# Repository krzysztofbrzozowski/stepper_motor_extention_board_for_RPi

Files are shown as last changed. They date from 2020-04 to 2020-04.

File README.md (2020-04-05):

# Stepper motor extention board for Raspberry Pi

Stepper motor extention board for Raspberry Pi Krzysztof Brzozowski (https://krzysztofbrzozowski.pl/projekt/steronik-silnikow-krokowych-rpi-kontroler-aku-usbc/)

Stepper motor extention board for Raspberry Pi Krzysztof Brzozowski (https://krzysztofbrzozowski.pl/projekt/steronik-silnikow-krokowych-rpi-kontroler-aku-usbc/)

Simple extension board for controlling stepper motors (up to 3). Board contains Li-Po battery controller (2-4s). It is also possible to charge battery via USB C. Basic firmware you can find here [stepper_motor_extention_board_firmware.git](https://github.com/krzysztofbrzozowski/stepper_motor_extention_board_firmware.git).
Controller is using simple algorithm for controlling ttepper motors [packets table](https://krzysztofbrzozowski.pl/media/2020/04/05/packet_encoding.png).

Whole project is describerd in polish on my webpage: https://krzysztofbrzozowski.pl/projekt/steronik-silnikow-krokowych-rpi-kontroler-aku-usbc/

## Repository Contents

- **/PCB** - Eagle PCB and schematic files, schematic in PDF

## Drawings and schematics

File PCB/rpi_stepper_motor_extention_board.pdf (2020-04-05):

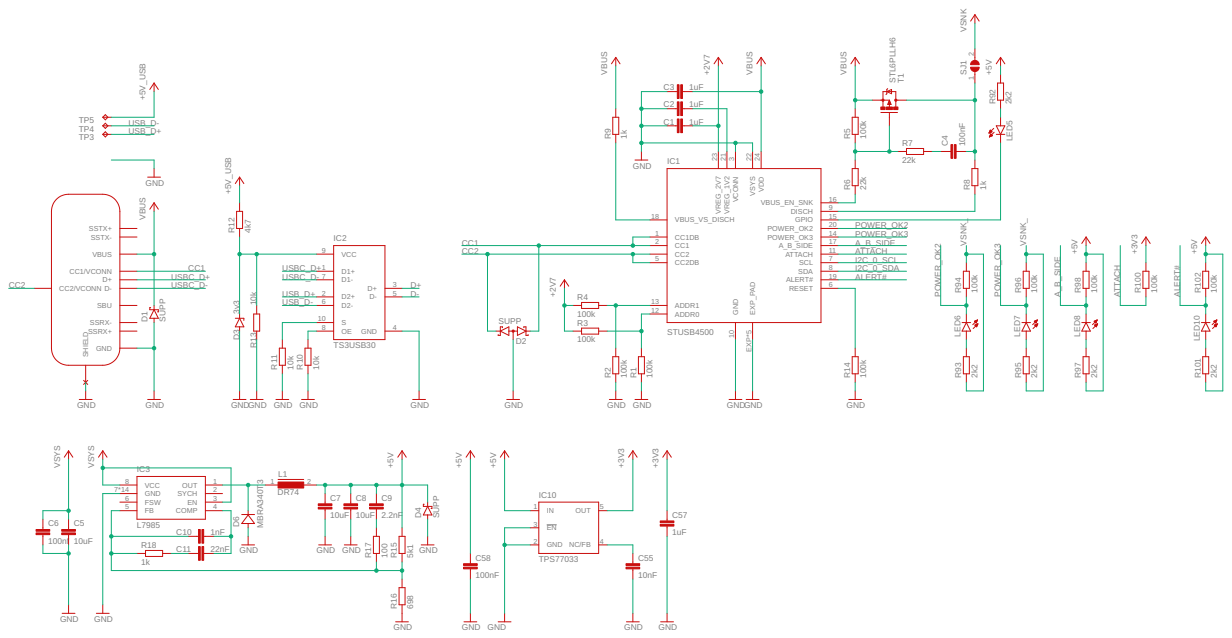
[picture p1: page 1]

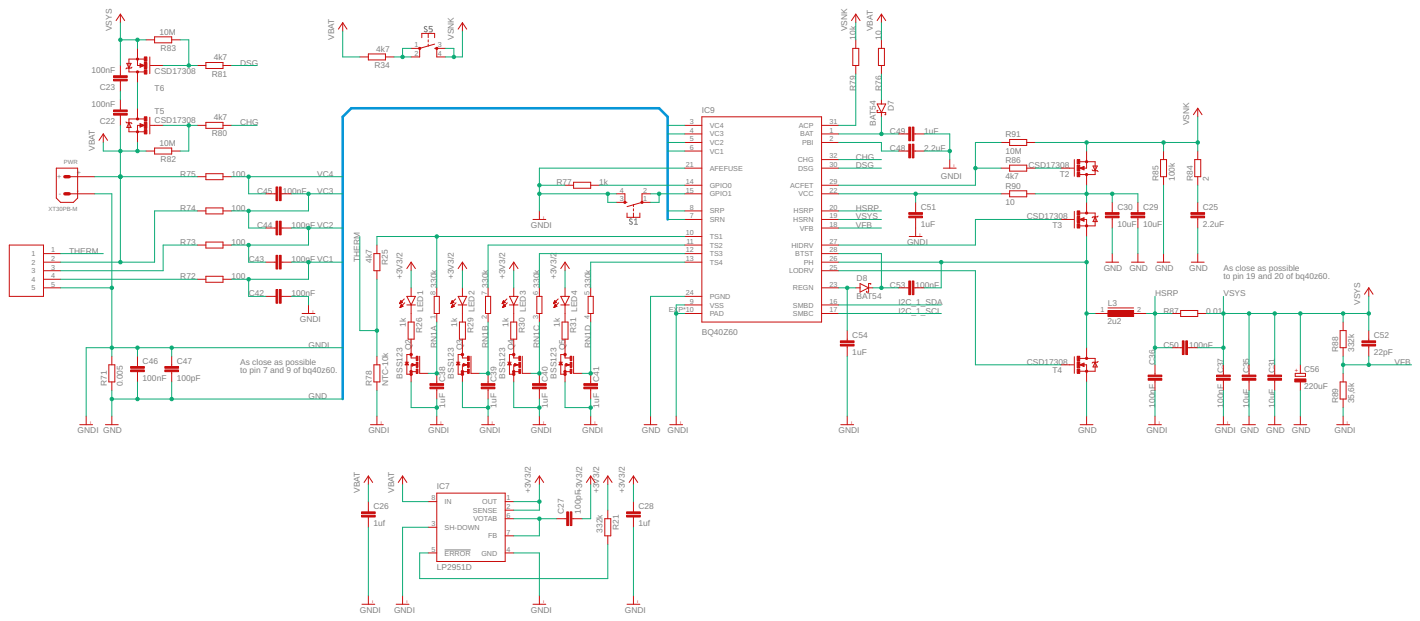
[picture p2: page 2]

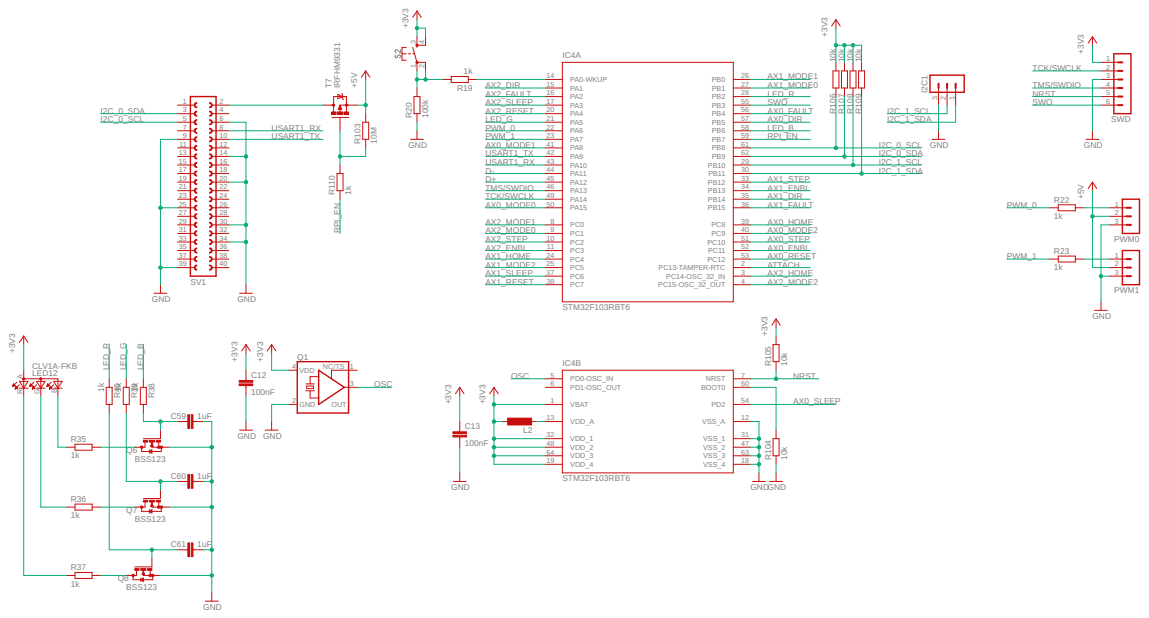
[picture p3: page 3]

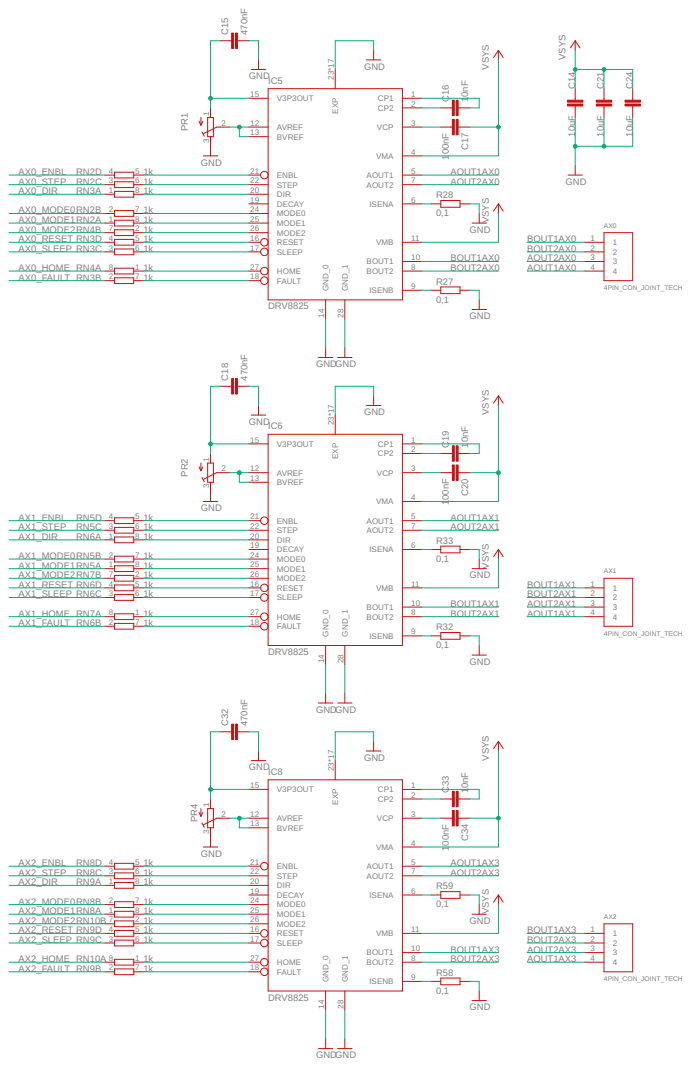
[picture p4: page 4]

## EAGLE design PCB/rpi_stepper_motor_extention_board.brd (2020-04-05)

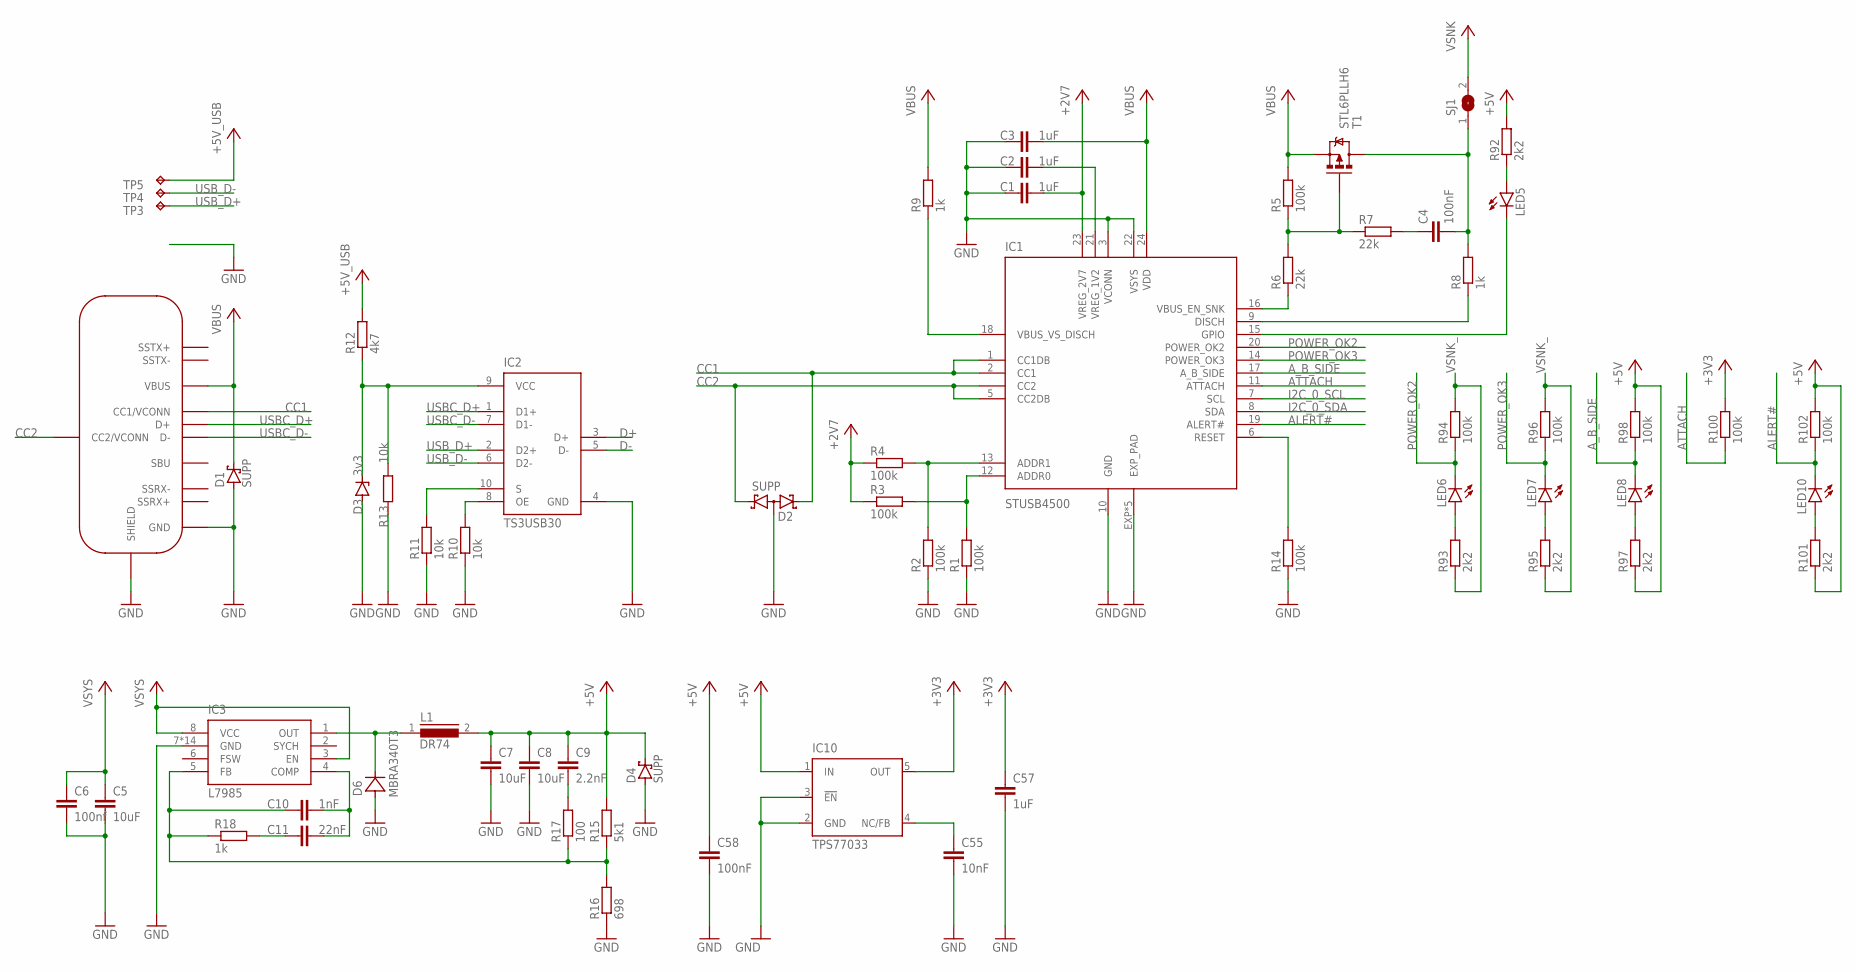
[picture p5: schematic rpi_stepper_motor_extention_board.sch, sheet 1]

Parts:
C1, C2, C57: 1uF; C0402K
C3: 1uF; C0603
C4, C58: 100nF; C0402K
C5: 10uF; C1206K
C6: 100nf; C0402K
C7, C8: 10uF; C1210
C9: 2.2nF; C0402K
C10: 1nF; C0402K
C11: 22nF; C0402K
C55: 10nF; C0402K
CON1: USB-TYPE-CHYBRID; USB-TYPE-C-HYBRID
D1, D4: SUPP; SOD123FL
D2: SUPP; SOT23
D3: 3v3; SOD80C
D6: MBRA340T3; SMA
IC1: STUSB4500; QFN50P400X400X90-25T270
IC2: TS3USB30; QFN40P180X145X55-10
IC3: L7985; SOIC127P600X170-8
IC10: TPS77033; SOT23-DBV
L1: DR74
LED5, LED6, LED7, LED8, LED10: LEDCHIPLED_0603; CHIPLED_0603
R1, R2, R3, R4, R5, R14, R94, R96, R98, R100, R102: 100k; R0402
R6, R7: 22k; R0402
R8, R9: 1k; R0603
R10, R11, R13: 10k; R0402
R12: 4k7; R0402
R15: 5k1; R0805
R16: 698; R0805
R17: 100; R0402
R18: 1k; R0402
R92, R93, R95, R97, R101: 2k2; R0402
SJ1: SJ
T1: STL6PLLH6; POWERPAK1212-8
TP3, TP4, TP5: TPB1,27; B1,27

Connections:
+2V7: C1.2, IC1.23 (VREG_2V7), R3.1, R4.1
+3V3: C57.1, IC10.5 (OUT), R100.2; also elsewhere on the board
+5V: C7.1, C8.1, C9.1, C58.1, D4.C, IC10.1 (IN), L1.2, R15.2, R92.2, R97.1, R98.2, R101.1, R102.2; also elsewhere on the board
+5V_USB: R12.2, TP5.TP
ALERT#: IC1.19 (ALERT#), LED10.C, R102.1
ATTACH: IC1.11 (ATTACH), R100.1; also elsewhere on the board
A_B_SIDE: IC1.17 (A_B_SIDE), LED8.C, R98.1
CC1: CON1.5 (CC1/VCONN), D2.2 (K2), IC1.1 (CC1DB), IC1.2 (CC1)
CC2: CON1.B5 (CC2/VCONN), D2.1 (K1), IC1.4 (CC2), IC1.5 (CC2DB)
D+: IC2.3 (D+); also elsewhere on the board
D-: IC2.5 (D-); also elsewhere on the board
GND: C1.1, C2.1, C3.1, C5.2, C6.2, C7.2, C8.2, C55.2, C57.2, C58.2, CON1.1 (GND), CON1.12 (GND), CON1.B1 (GND), CON1.B12 (GND), CON1.P$1 (SHIELD), CON1.P$2 (SHIELD), CON1.P$3 (SHIELD), CON1.P$4 (SHIELD), CON1.P$7 (SHIELD), CON1.P$8 (SHIELD), CON1.P$9 (SHIELD), CON1.P$10 (SHIELD), CON1.P$11 (SHIELD), CON1.P$12 (SHIELD), CON1.P$13 (SHIELD), CON1.P$14 (SHIELD), CON1.P$15 (SHIELD), CON1.P$16 (SHIELD), CON1.P$17 (SHIELD), CON1.P$18 (SHIELD), CON1.P$19 (SHIELD), CON1.P$20 (SHIELD), CON1.P$21 (SHIELD), CON1.P$22 (SHIELD), CON1.P$23 (SHIELD), CON1.P$24 (SHIELD), CON1.P$25 (SHIELD), CON1.P$26 (SHIELD), CON1.P$27 (SHIELD), CON1.P$28 (SHIELD), CON1.P$29 (SHIELD), CON1.P$30 (SHIELD), CON1.P$31 (SHIELD), CON1.P$32 (SHIELD), CON1.P$33 (SHIELD), CON1.P$34 (SHIELD), CON1.P$35 (SHIELD), D1.A, D2.3 (AA), D3.A, D4.A, D6.A, IC1.3 (VCONN), IC1.10 (GND), IC1.22 (VSYS), IC1.EXP (EXP_PAD), IC1.P$1 (EXP_PAD), IC1.P$2 (EXP_PAD), IC1.P$3 (EXP_PAD), IC1.P$4 (EXP_PAD), IC2.4 (GND), IC3.7 (GND), IC3.EXP (GND), IC3.P$1 (GND), IC3.P$2 (GND), IC3.P$3 (GND), IC3.P$4 (GND), IC3.P$5 (GND), IC3.P$6 (GND), IC3.P$7 (GND), IC3.P$8 (GND), IC3.P$9 (GND), IC3.P$10 (GND), IC3.P$11 (GND), IC3.P$12 (GND), IC10.2 (GND), IC10.3 (!EN), R1.1, R2.1, R10.1, R11.1, R13.2, R14.1, R16.1; also elsewhere on the board
I2C_0_SCL: IC1.7 (SCL); also elsewhere on the board
I2C_0_SDA: IC1.8 (SDA); also elsewhere on the board
unnamed: IC1.12 (ADDR0), R1.2, R3.2
unnamed: IC1.13 (ADDR1), R2.2, R4.2
unnamed: C2.2, IC1.21 (VREG_1V2)
unnamed: C4.1, R7.2
unnamed: IC1.16 (VBUS_EN_SNK), R6.1
unnamed: R5.1, R6.2, R7.1, T1.G
unnamed: IC1.18 (VBUS_VS_DISCH), R9.1
unnamed: IC1.9 (DISCH), R8.1
unnamed: IC2.8 (OE), R10.2
unnamed: IC2.10 (S), R11.2
unnamed: D6.C, IC3.1 (OUT), L1.1
unnamed: D3.C, IC2.9 (VCC), R12.1, R13.1
unnamed: IC1.6 (RESET), R14.2
unnamed: C10.1, IC3.5 (FB), R15.1, R16.2, R17.1, R18.1
unnamed: C9.2, R17.2
unnamed: C10.2, C11.2, IC3.4 (COMP)
unnamed: C11.1, R18.2
unnamed: C55.1, IC10.4 (NC/FB)
unnamed: LED5.A, R92.1
unnamed: LED6.A, R93.2
unnamed: LED10.A, R101.2
unnamed: LED7.A, R95.2
unnamed: IC1.15 (GPIO), LED5.C
unnamed: LED8.A, R97.2
POWER_OK2: IC1.20 (POWER_OK2), LED6.C, R94.1
POWER_OK3: IC1.14 (POWER_OK3), LED7.C, R96.1
USBC_D+: CON1.6 (D+), CON1.B6 (D+), IC2.1 (D1+)
USBC_D-: CON1.7 (D-), CON1.B7 (D-), IC2.7 (D1-)
USB_D+: IC2.2 (D2+), TP3.TP
USB_D-: IC2.6 (D2-), TP4.TP
VBUS: C3.2, CON1.4 (VBUS), CON1.9 (VBUS), CON1.B4 (VBUS), CON1.B9 (VBUS), D1.C, IC1.24 (VDD), R5.2, R9.2, T1.S1 (S), T1.S2 (S), T1.S3 (S)
VSNK: SJ1.2; also elsewhere on the board
VSNK_: C4.2, R8.2, R93.1, R94.2, R95.1, R96.2, SJ1.1, T1.D1 (D), T1.D2 (D), T1.D3 (D), T1.D4 (D), T1.DPAD (D)
VSYS: C5.1, C6.1, IC3.3 (EN), IC3.8 (VCC); also elsewhere on the board

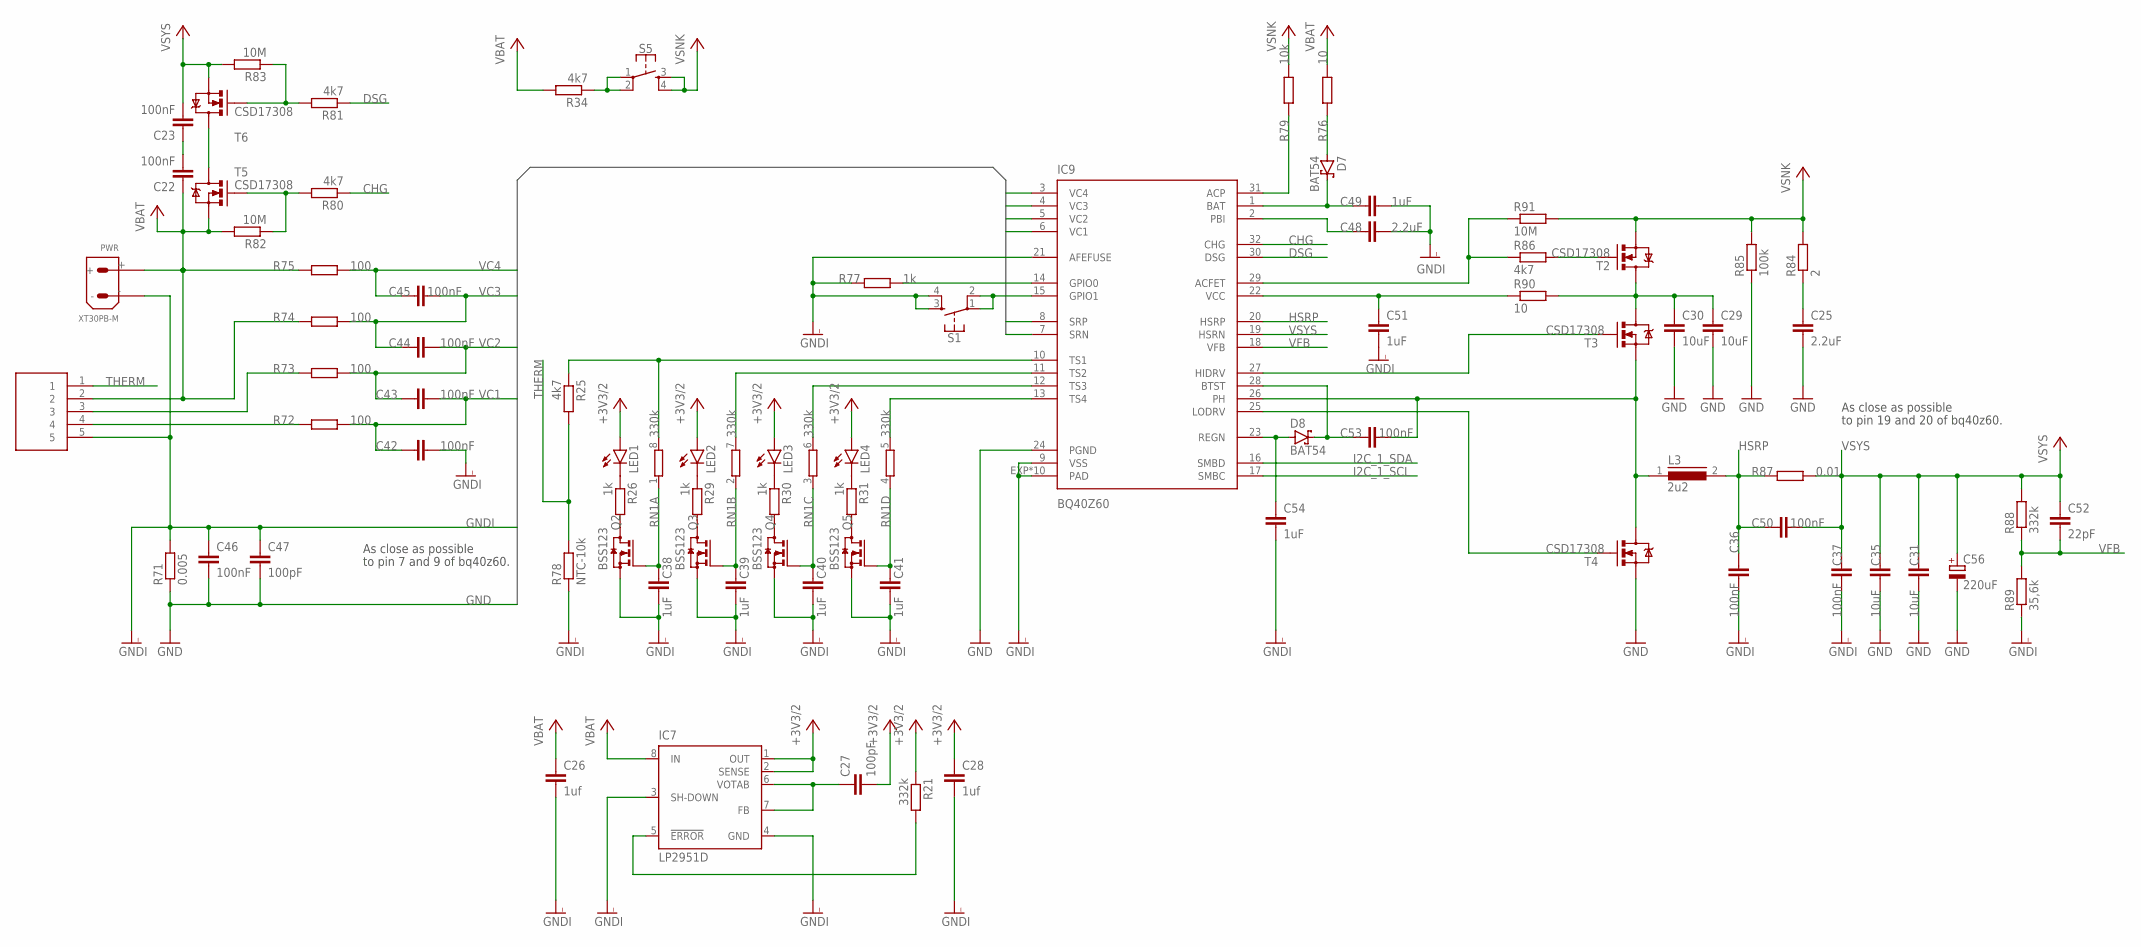
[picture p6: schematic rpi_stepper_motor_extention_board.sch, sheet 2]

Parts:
C22, C23: 100nF; C0603K
C25, C48: 2.2uF; C0603K
C26, C28: 1uf; C0402
C27, C47: 100pF; C0402
C29, C30, C31, C35: 10uF; C1206K
C36, C37, C42, C43, C44, C45, C50, C53: 100nF; C0402K
C38, C39, C40, C41: 1uF; C0402K
C46: 100nF; C0402
C49, C51, C54: 1uF; C0603K
C52: 22pF; C0402K
C56: 220uF; 153CLV-0605
D7, D8: BAT54; SOD123FL
IC7: LP2951D; SO08
IC9: BQ40Z60; QFN50P500X500X100-33T345
L3: 2u2; DR74
LED1, LED2, LED3, LED4: LEDCHIPLED_0603; CHIPLED_0603
PWR: XT30PB-M
Q2, Q3, Q4, Q5: BSS123; SOT23
R21: 332k; R0402
R25, R34, R80, R81, R86: 4k7; R0402
R26, R29, R30, R31, R77: 1k; R0402
R71: 0.005; R2010
R72, R73, R74, R75: 100; R0603
R76: 10; R0402
R78: NTC-10k; R0603
R79: 10k; R0402
R82, R83, R91: 10M; R0402
R84: 2; R0603
R85: 100k; R0402
R87: 0.01; R2512
R88: 332k; R0805
R89: 35,6k; R0805
R90: 10; R1206
RN1: 330k; 0603-ARC
S1, S5: MOMENTARY-SWITCH-SPST-2-SMD-4.6X2.8MM; TACTILE_SWITCH_SMD_4.6X2.8MM
T2, T3, T4, T5, T6: CSD17308; POWERPAK1212-8
U$1: 5PIN_CON_JOINT_TECH

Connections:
+3V3/2: C27.2, C28.1, IC7.1 (OUT), IC7.2 (SENSE), LED1.A, LED2.A, LED3.A, LED4.A, R21.1
CHG: IC9.32 (CHG), R80.1
DSG: IC9.30 (DSG), R81.1
GND: C25.2, C29.2, C30.2, C31.2, C35.2, C46.2, C47.2, C56.-, IC9.7 (SRN), IC9.24 (PGND), R71.1, R85.1, T4.S1 (S), T4.S2 (S), T4.S3 (S); also elsewhere on the board
GNDI: C26.2, C28.2, C36.2, C37.2, C38.2, C39.2, C40.2, C41.2, C42.1, C46.1, C47.1, C48.2, C49.2, C51.2, C54.2, IC7.3 (SH-DOWN), IC7.4 (GND), IC9.8 (SRP), IC9.9 (VSS), IC9.21 (AFEFUSE), IC9.EXP (PAD), IC9.P$1 (PAD), IC9.P$2 (PAD), IC9.P$3 (PAD), IC9.P$4 (PAD), IC9.P$5 (PAD), IC9.P$6 (PAD), IC9.P$7 (PAD), IC9.P$8 (PAD), IC9.P$9 (PAD), PWR.-, Q2.2 (S), Q3.2 (S), Q4.2 (S), Q5.2 (S), R71.2, R77.1, R78.1, R89.1, S1.3, S1.4, U$1.5
HSRP: C36.1, C50.1, IC9.20 (HSRP), L3.2, R87.1
I2C_1_SCL: IC9.17 (SMBC); also elsewhere on the board
I2C_1_SDA: IC9.16 (SMBD); also elsewhere on the board
unnamed: LED1.C, R26.1
unnamed: LED2.C, R29.1
unnamed: LED3.C, R30.1
unnamed: LED4.C, R31.1
unnamed: C27.1, IC7.6 (VOTAB), IC7.7 (FB)
unnamed: Q2.3 (D), R26.2
unnamed: Q3.3 (D), R29.2
unnamed: IC7.5 (!ERROR), R21.2
unnamed: Q5.3 (D), R31.2
unnamed: Q4.3 (D), R30.2
unnamed: R34.1, S5.1, S5.2
unnamed: C38.1, Q2.1 (G), RN1.1
unnamed: C48.1, IC9.2 (PBI)
unnamed: IC9.10 (TS1), R25.1, RN1.8 (2)
unnamed: IC9.11 (TS2), RN1.7 (2)
unnamed: IC9.12 (TS3), RN1.6 (2)
unnamed: IC9.13 (TS4), RN1.5 (2)
unnamed: C39.1, Q3.1 (G), RN1.2 (1)
unnamed: D7.A, R76.1
unnamed: R72.1, U$1.4
unnamed: C40.1, Q4.1 (G), RN1.3 (1)
unnamed: C41.1, Q5.1 (G), RN1.4 (1)
unnamed: C49.1, D7.C, IC9.1 (BAT)
unnamed: R73.1, U$1.3
unnamed: IC9.14 (GPIO0), R77.2
unnamed: IC9.15 (GPIO1), S1.1, S1.2
unnamed: IC9.31 (ACP), R79.1
unnamed: T5.D1 (D), T5.D2 (D), T5.D3 (D), T5.D4 (D), T5.DPAD (D), T6.D1 (D), T6.D2 (D), T6.D3 (D), T6.D4 (D), T6.DPAD (D)
unnamed: R80.2, R82.1, T5.G
unnamed: R81.2, R83.1, T6.G
unnamed: C25.1, R84.1
unnamed: C22.2, C23.1
unnamed: C29.1, C30.1, R90.2, T2.D1 (D), T2.D2 (D), T2.D3 (D), T2.D4 (D), T2.DPAD (D), T3.D1 (D), T3.D2 (D), T3.D3 (D), T3.D4 (D), T3.DPAD (D)
unnamed: C53.2, IC9.26 (PH), L3.1, T3.S1 (S), T3.S2 (S), T3.S3 (S), T4.D1 (D), T4.D2 (D), T4.D3 (D), T4.D4 (D), T4.DPAD (D)
unnamed: R86.2, T2.G
unnamed: IC9.27 (HIDRV), T3.G
unnamed: IC9.25 (LODRV), T4.G
unnamed: IC9.29 (ACFET), R86.1, R91.1
unnamed: C51.1, IC9.22 (VCC), R90.1
unnamed: C54.1, D8.A, IC9.23 (REGN)
unnamed: C53.1, D8.C, IC9.28 (BTST)
THERM: R25.2, R78.2, U$1.1
VBAT: C22.1, C26.1, IC7.8 (IN), PWR.+, R34.2, R74.1, R75.1, R76.2, R82.2, T5.S1 (S), T5.S2 (S), T5.S3 (S), U$1.2
VC1: C42.2, C43.1, IC9.6 (VC1), R72.2
VC2: C43.2, C44.1, IC9.5 (VC2), R73.2
VC3: C44.2, C45.1, IC9.4 (VC3), R74.2
VC4: C45.2, IC9.3 (VC4), R75.2
VFB: C52.2, IC9.18 (VFB), R88.1, R89.2
VSNK: R79.2, R84.2, R85.2, R91.2, S5.3, S5.4, T2.S1 (S), T2.S2 (S), T2.S3 (S); also elsewhere on the board
VSYS: C23.2, C31.1, C35.1, C37.1, C50.2, C52.1, C56.+, IC9.19 (HSRN), R83.2, R87.2, R88.2, T6.S1 (S), T6.S2 (S), T6.S3 (S); also elsewhere on the board

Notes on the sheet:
As close as possible
to pin 7 and 9 of bq40z60.
to pin 19 and 20 of bq40z60.

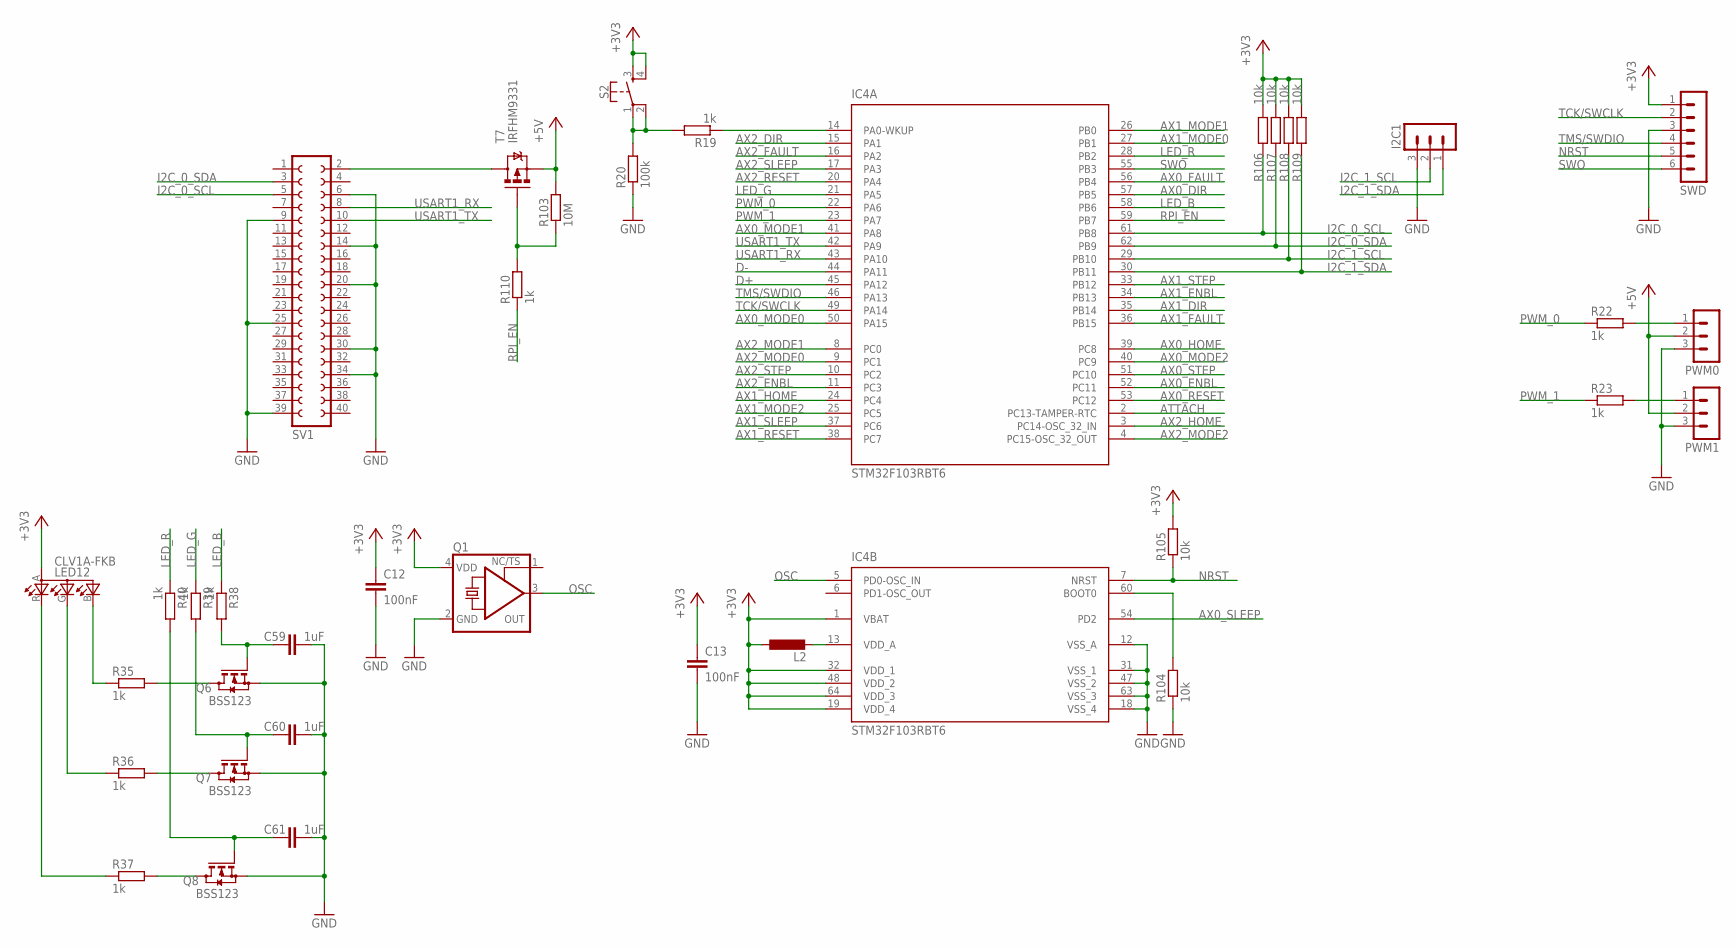
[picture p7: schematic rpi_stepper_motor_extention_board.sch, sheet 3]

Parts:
C12, C13: 100nF; C0402K
C59, C60, C61: 1uF; C0402K
I2C1: MA03-1
IC4: STM32F103RBT6; QFP50P1200X1200X160-64
L2: L-EUL2012C; L2012C
LED12: CLV1A-FKB
PWM0, PWM1: MA03-1
Q1: KXO-PXO/XO-V95; 2.5X2.0_KXO-V95
Q6, Q7, Q8: BSS123; SOT23
R19, R22, R23, R35, R36, R37, R38, R39, R40, R110: 1k; R0402
R20: 100k; R0402
R103: 10M; R0402
R104, R105, R106, R107, R108, R109: 10k; R0402
S2: MOMENTARY-SWITCH-SPST-2-SMD-4.6X2.8MM; TACTILE_SWITCH_SMD_4.6X2.8MM
SV1: FE20-2
SWD: MA06-1
T7: IRFHM9331; POWERPAK1212-8

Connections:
+3V3: C12.1, C13.1, IC4.1 (VBAT), IC4.19 (VDD_4), IC4.32 (VDD_1), IC4.48 (VDD_2), IC4.64 (VDD_3), L2.1, LED12.A (ANODE), Q1.4 (VDD), R105.2, R106.2, R107.2, R108.2, R109.2, S2.3, S2.4, SWD.1; also elsewhere on the board
+5V: PWM0.2, PWM1.2, R103.2, T7.S1 (S), T7.S2 (S), T7.S3 (S); also elsewhere on the board
ATTACH: IC4.2 (PC13-TAMPER-RTC); also elsewhere on the board
AX0_DIR: IC4.57 (PB5); also elsewhere on the board
AX0_ENBL: IC4.52 (PC11); also elsewhere on the board
AX0_FAULT: IC4.56 (PB4); also elsewhere on the board
AX0_HOME: IC4.39 (PC8); also elsewhere on the board
AX0_MODE0: IC4.50 (PA15); also elsewhere on the board
AX0_MODE1: IC4.41 (PA8); also elsewhere on the board
AX0_MODE2: IC4.40 (PC9); also elsewhere on the board
AX0_RESET: IC4.53 (PC12); also elsewhere on the board
AX0_SLEEP: IC4.54 (PD2); also elsewhere on the board
AX0_STEP: IC4.51 (PC10); also elsewhere on the board
AX1_DIR: IC4.35 (PB14); also elsewhere on the board
AX1_ENBL: IC4.34 (PB13); also elsewhere on the board
AX1_FAULT: IC4.36 (PB15); also elsewhere on the board
AX1_HOME: IC4.24 (PC4); also elsewhere on the board
AX1_MODE0: IC4.27 (PB1); also elsewhere on the board
AX1_MODE1: IC4.26 (PB0); also elsewhere on the board
AX1_MODE2: IC4.25 (PC5); also elsewhere on the board
AX1_RESET: IC4.38 (PC7); also elsewhere on the board
AX1_SLEEP: IC4.37 (PC6); also elsewhere on the board
AX1_STEP: IC4.33 (PB12); also elsewhere on the board
AX2_DIR: IC4.15 (PA1); also elsewhere on the board
AX2_ENBL: IC4.11 (PC3); also elsewhere on the board
AX2_FAULT: IC4.16 (PA2); also elsewhere on the board
AX2_HOME: IC4.3 (PC14-OSC_32_IN); also elsewhere on the board
AX2_MODE0: IC4.9 (PC1); also elsewhere on the board
AX2_MODE1: IC4.8 (PC0); also elsewhere on the board
AX2_MODE2: IC4.4 (PC15-OSC_32_OUT); also elsewhere on the board
AX2_RESET: IC4.20 (PA4); also elsewhere on the board
AX2_SLEEP: IC4.17 (PA3); also elsewhere on the board
AX2_STEP: IC4.10 (PC2); also elsewhere on the board
D+: IC4.45 (PA12); also elsewhere on the board
D-: IC4.44 (PA11); also elsewhere on the board
GND: C12.2, C13.2, C59.2, C60.2, C61.2, I2C1.3, IC4.12 (VSS_A), IC4.18 (VSS_4), IC4.31 (VSS_1), IC4.47 (VSS_2), IC4.63 (VSS_3), PWM0.3, PWM1.3, Q1.2 (GND), Q6.2 (S), Q7.2 (S), Q8.2 (S), R20.1, R104.1, SV1.6, SV1.9, SV1.14, SV1.20, SV1.25, SV1.30, SV1.34, SV1.39, SWD.3; also elsewhere on the board
I2C_0_SCL: IC4.61 (PB8), R106.1, SV1.5; also elsewhere on the board
I2C_0_SDA: IC4.62 (PB9), R107.1, SV1.3; also elsewhere on the board
I2C_1_SCL: I2C1.2, IC4.29 (PB10), R108.1; also elsewhere on the board
I2C_1_SDA: I2C1.1, IC4.30 (PB11), R109.1; also elsewhere on the board
LED_B: IC4.58 (PB6), R38.1
LED_G: IC4.21 (PA5), R39.1
LED_R: IC4.28 (PB2), R40.1
unnamed: IC4.13 (VDD_A), L2.2
unnamed: LED12.G (CGREEN), R36.1
unnamed: C59.1, Q6.1 (G), R38.2
unnamed: IC4.14 (PA0-WKUP), R19.1
unnamed: LED12.R (CRED), R37.1
unnamed: LED12.B (CBLUE), R35.1
unnamed: Q8.3 (D), R37.2
unnamed: Q7.3 (D), R36.2
unnamed: Q6.3 (D), R35.2
unnamed: C60.1, Q7.1 (G), R39.2
unnamed: C61.1, Q8.1 (G), R40.2
unnamed: SV1.2, T7.D1 (D), T7.D2 (D), T7.D3 (D), T7.D4 (D), T7.DPAD (D)
unnamed: IC4.60 (BOOT0), R104.2
unnamed: R103.1, R110.2, T7.G
unnamed: R19.2, R20.2, S2.1, S2.2
unnamed: PWM0.1, R22.2
unnamed: PWM1.1, R23.2
NRST: IC4.7 (NRST), R105.1, SWD.5
OSC: IC4.5 (PD0-OSC_IN), Q1.3 (OUT)
PWM_0: IC4.22 (PA6), R22.1
PWM_1: IC4.23 (PA7), R23.1
RPI_EN: IC4.59 (PB7), R110.1
SWO: IC4.55 (PB3), SWD.6
TCK/SWCLK: IC4.49 (PA14), SWD.2
TMS/SWDIO: IC4.46 (PA13), SWD.4
USART1_RX: IC4.43 (PA10), SV1.8
USART1_TX: IC4.42 (PA9), SV1.10

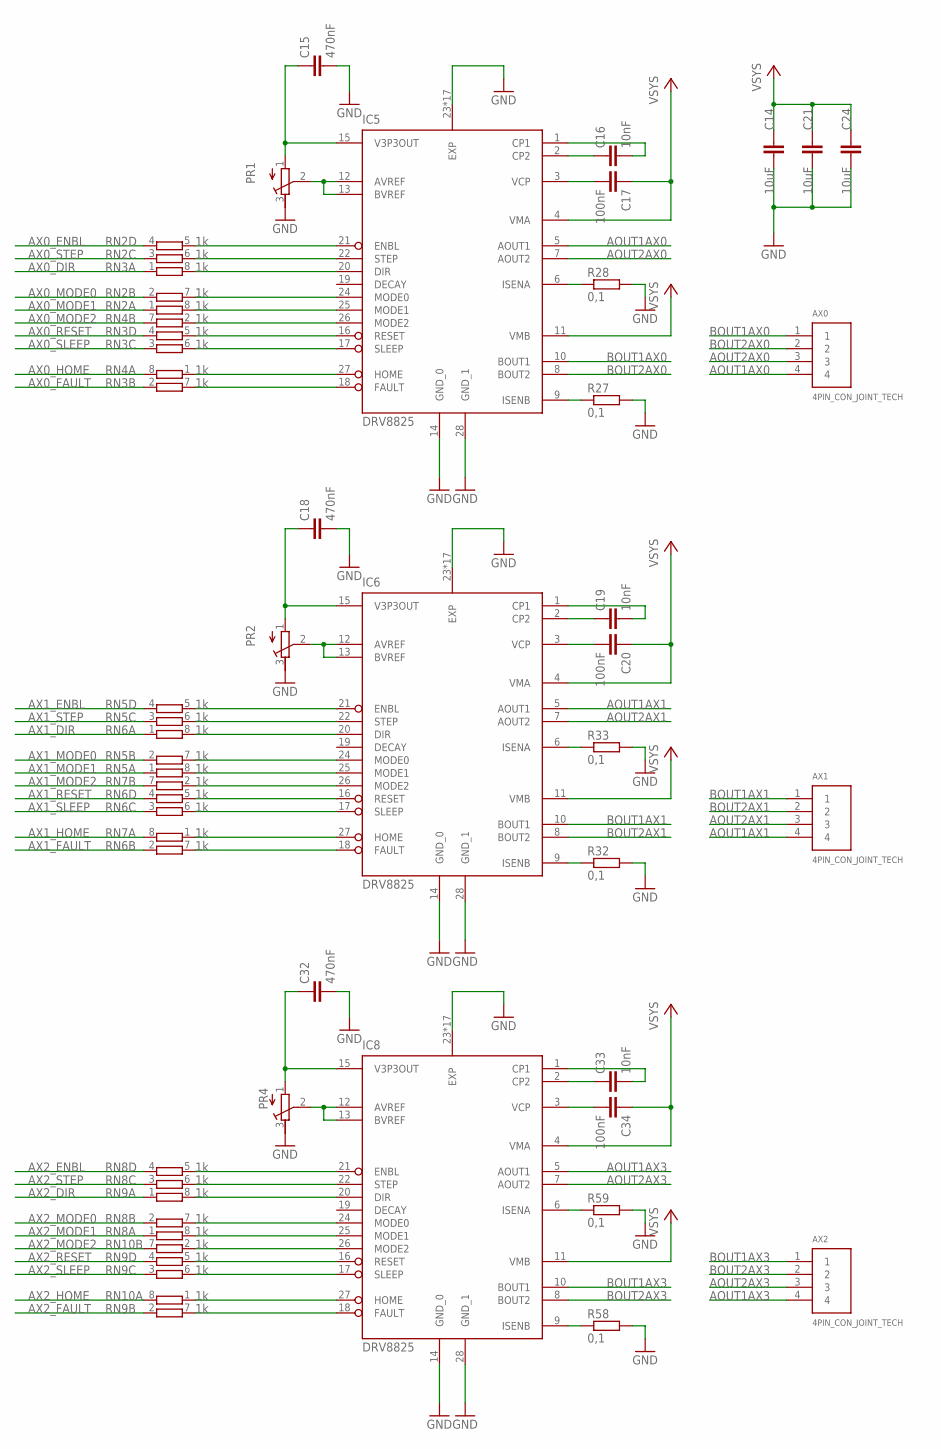
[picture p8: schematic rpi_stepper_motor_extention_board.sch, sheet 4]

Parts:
AX0, AX1, AX2: 4PIN_CON_JOINT_TECH
C14, C21, C24: 10uF; C1206K
C15, C18, C32: 470nF; C0402K
C16, C19, C33: 10nF; C0402K
C17, C20, C34: 100nF; C0402K
IC5, IC6, IC8: DRV8825; SOP65P640X120-28
PR1, PR2, PR4: R-TRIMM3224J; RTRIM3224J
R27, R28, R32, R33, R58, R59: 0,1; R0805
RN2, RN3, RN4, RN5, RN6, RN7, RN8, RN9, RN10: 1k; 0603-ARC

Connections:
AOUT1AX0: AX0.4, IC5.5 (AOUT1)
AOUT1AX1: AX1.4, IC6.5 (AOUT1)
AOUT1AX3: AX2.4, IC8.5 (AOUT1)
AOUT2AX0: AX0.3, IC5.7 (AOUT2)
AOUT2AX1: AX1.3, IC6.7 (AOUT2)
AOUT2AX3: AX2.3, IC8.7 (AOUT2)
AX0_DIR: RN3.1; also elsewhere on the board
AX0_ENBL: RN2.4 (1); also elsewhere on the board
AX0_FAULT: RN3.2 (1); also elsewhere on the board
AX0_HOME: RN4.8 (2); also elsewhere on the board
AX0_MODE0: RN2.2 (1); also elsewhere on the board
AX0_MODE1: RN2.1; also elsewhere on the board
AX0_MODE2: RN4.7 (2); also elsewhere on the board
AX0_RESET: RN3.4 (1); also elsewhere on the board
AX0_SLEEP: RN3.3 (1); also elsewhere on the board
AX0_STEP: RN2.3 (1); also elsewhere on the board
AX1_DIR: RN6.1; also elsewhere on the board
AX1_ENBL: RN5.4 (1); also elsewhere on the board
AX1_FAULT: RN6.2 (1); also elsewhere on the board
AX1_HOME: RN7.8 (2); also elsewhere on the board
AX1_MODE0: RN5.2 (1); also elsewhere on the board
AX1_MODE1: RN5.1; also elsewhere on the board
AX1_MODE2: RN7.7 (2); also elsewhere on the board
AX1_RESET: RN6.4 (1); also elsewhere on the board
AX1_SLEEP: RN6.3 (1); also elsewhere on the board
AX1_STEP: RN5.3 (1); also elsewhere on the board
AX2_DIR: RN9.1; also elsewhere on the board
AX2_ENBL: RN8.4 (1); also elsewhere on the board
AX2_FAULT: RN9.2 (1); also elsewhere on the board
AX2_HOME: RN10.8 (2); also elsewhere on the board
AX2_MODE0: RN8.2 (1); also elsewhere on the board
AX2_MODE1: RN8.1; also elsewhere on the board
AX2_MODE2: RN10.7 (2); also elsewhere on the board
AX2_RESET: RN9.4 (1); also elsewhere on the board
AX2_SLEEP: RN9.3 (1); also elsewhere on the board
AX2_STEP: RN8.3 (1); also elsewhere on the board
BOUT1AX0: AX0.1, IC5.10 (BOUT1)
BOUT1AX1: AX1.1, IC6.10 (BOUT1)
BOUT1AX3: AX2.1, IC8.10 (BOUT1)
BOUT2AX0: AX0.2, IC5.8 (BOUT2)
BOUT2AX1: AX1.2, IC6.8 (BOUT2)
BOUT2AX3: AX2.2, IC8.8 (BOUT2)
GND: C14.2, C15.2, C18.2, C21.2, C24.2, C32.2, IC5.14 (GND_0), IC5.23 (EXP), IC5.28 (GND_1), IC5.EXP, IC5.P$1 (EXP), IC5.P$2 (EXP), IC5.P$3 (EXP), IC5.P$4 (EXP), IC5.P$5 (EXP), IC5.P$6 (EXP), IC5.P$7 (EXP), IC5.P$8 (EXP), IC5.P$9 (EXP), IC5.P$10 (EXP), IC5.P$11 (EXP), IC5.P$12 (EXP), IC5.P$13 (EXP), IC5.P$14 (EXP), IC5.P$15 (EXP), IC6.14 (GND_0), IC6.23 (EXP), IC6.28 (GND_1), IC6.EXP, IC6.P$1 (EXP), IC6.P$2 (EXP), IC6.P$3 (EXP), IC6.P$4 (EXP), IC6.P$5 (EXP), IC6.P$6 (EXP), IC6.P$7 (EXP), IC6.P$8 (EXP), IC6.P$9 (EXP), IC6.P$10 (EXP), IC6.P$11 (EXP), IC6.P$12 (EXP), IC6.P$13 (EXP), IC6.P$14 (EXP), IC6.P$15 (EXP), IC8.14 (GND_0), IC8.23 (EXP), IC8.28 (GND_1), IC8.EXP, IC8.P$1 (EXP), IC8.P$2 (EXP), IC8.P$3 (EXP), IC8.P$4 (EXP), IC8.P$5 (EXP), IC8.P$6 (EXP), IC8.P$7 (EXP), IC8.P$8 (EXP), IC8.P$9 (EXP), IC8.P$10 (EXP), IC8.P$11 (EXP), IC8.P$12 (EXP), IC8.P$13 (EXP), IC8.P$14 (EXP), IC8.P$15 (EXP), PR1.3 (E), PR2.3 (E), PR4.3 (E), R27.2, R28.2, R32.2, R33.2, R58.2, R59.2; also elsewhere on the board
unnamed: IC5.21 (ENBL), RN2.5 (2)
unnamed: IC5.22 (STEP), RN2.6 (2)
unnamed: IC5.20 (DIR), RN3.8 (2)
unnamed: IC5.16 (RESET), RN3.5 (2)
unnamed: IC5.18 (FAULT), RN3.7 (2)
unnamed: IC5.24 (MODE0), RN2.7 (2)
unnamed: IC5.12 (AVREF), IC5.13 (BVREF), PR1.2 (S)
unnamed: IC5.25 (MODE1), RN2.8 (2)
unnamed: C15.1, IC5.15 (V3P3OUT), PR1.1 (A)
unnamed: IC5.17 (SLEEP), RN3.6 (2)
unnamed: C16.1, IC5.2 (CP2)
unnamed: C16.2, IC5.1 (CP1)
unnamed: IC5.9 (ISENB), R27.1
unnamed: IC5.6 (ISENA), R28.1
unnamed: C17.2, IC5.3 (VCP)
unnamed: IC5.26 (MODE2), RN4.2 (1)
unnamed: IC6.12 (AVREF), IC6.13 (BVREF), PR2.2 (S)
unnamed: C18.1, IC6.15 (V3P3OUT), PR2.1 (A)
unnamed: IC6.17 (SLEEP), RN6.6 (2)
unnamed: C19.1, IC6.2 (CP2)
unnamed: C19.2, IC6.1 (CP1)
unnamed: IC6.9 (ISENB), R32.1
unnamed: IC6.6 (ISENA), R33.1
unnamed: C20.2, IC6.3 (VCP)
unnamed: IC6.21 (ENBL), RN5.5 (2)
unnamed: IC6.22 (STEP), RN5.6 (2)
unnamed: IC6.20 (DIR), RN6.8 (2)
unnamed: IC6.16 (RESET), RN6.5 (2)
unnamed: IC6.18 (FAULT), RN6.7 (2)
unnamed: IC6.24 (MODE0), RN5.7 (2)
unnamed: IC6.25 (MODE1), RN5.8 (2)
unnamed: IC6.26 (MODE2), RN7.2 (1)
unnamed: IC5.27 (HOME), RN4.1
unnamed: IC8.27 (HOME), RN10.1
unnamed: IC6.27 (HOME), RN7.1
unnamed: IC8.12 (AVREF), IC8.13 (BVREF), PR4.2 (S)
unnamed: C32.1, IC8.15 (V3P3OUT), PR4.1 (A)
unnamed: IC8.17 (SLEEP), RN9.6 (2)
unnamed: C33.1, IC8.2 (CP2)
unnamed: C33.2, IC8.1 (CP1)
unnamed: IC8.9 (ISENB), R58.1
unnamed: IC8.6 (ISENA), R59.1
unnamed: C34.2, IC8.3 (VCP)
unnamed: IC8.21 (ENBL), RN8.5 (2)
unnamed: IC8.22 (STEP), RN8.6 (2)
unnamed: IC8.20 (DIR), RN9.8 (2)
unnamed: IC8.16 (RESET), RN9.5 (2)
unnamed: IC8.18 (FAULT), RN9.7 (2)
unnamed: IC8.24 (MODE0), RN8.7 (2)
unnamed: IC8.25 (MODE1), RN8.8 (2)
unnamed: IC8.26 (MODE2), RN10.2 (1)
VSYS: C14.1, C17.1, C20.1, C21.1, C24.1, C34.1, IC5.4 (VMA), IC5.11 (VMB), IC6.4 (VMA), IC6.11 (VMB), IC8.4 (VMA), IC8.11 (VMB); also elsewhere on the board

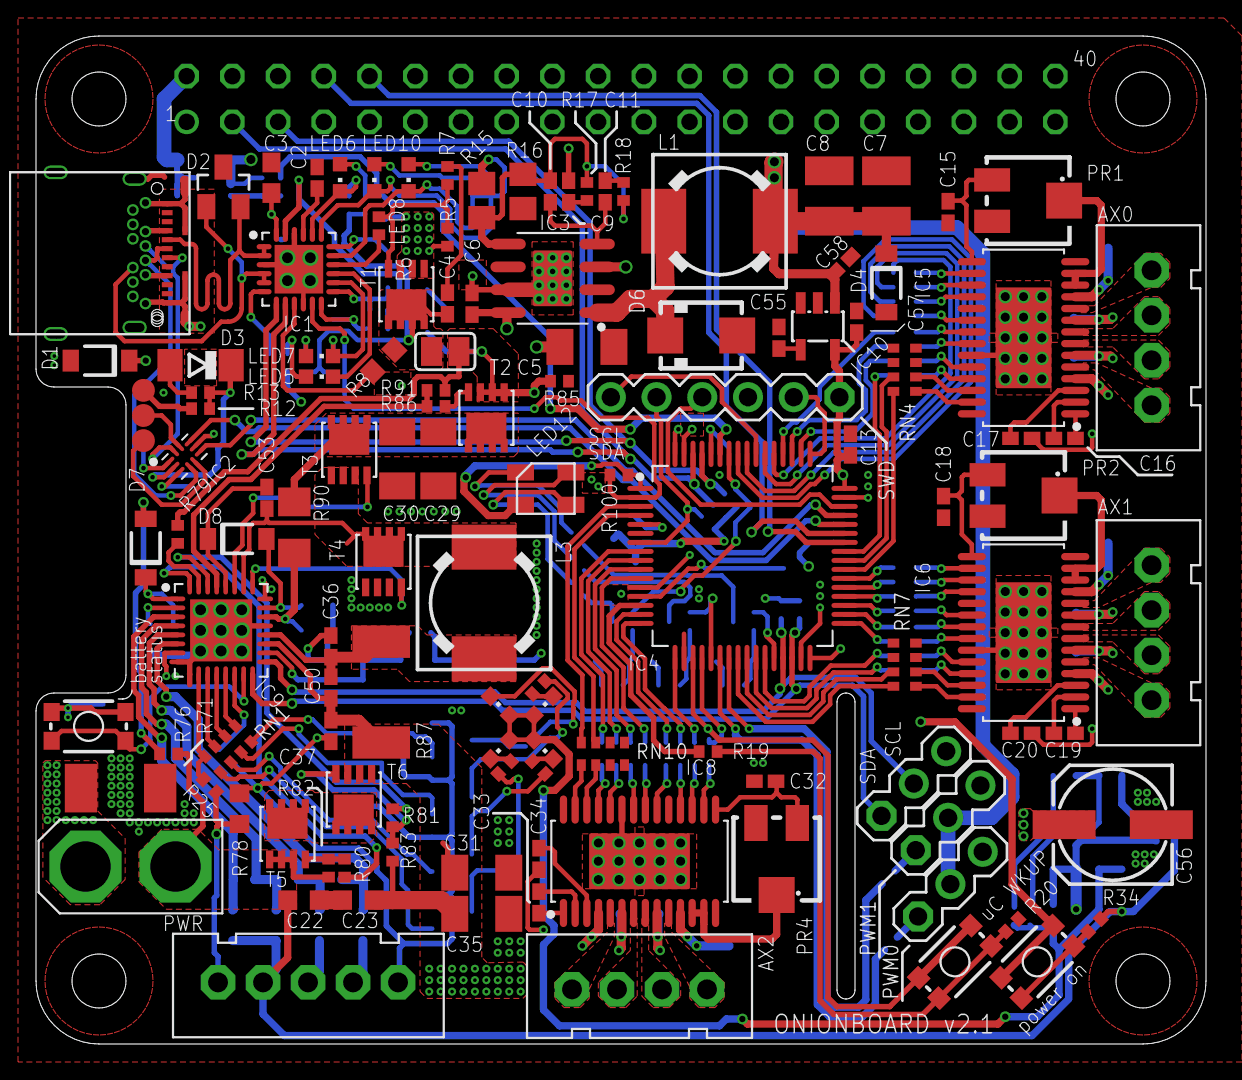
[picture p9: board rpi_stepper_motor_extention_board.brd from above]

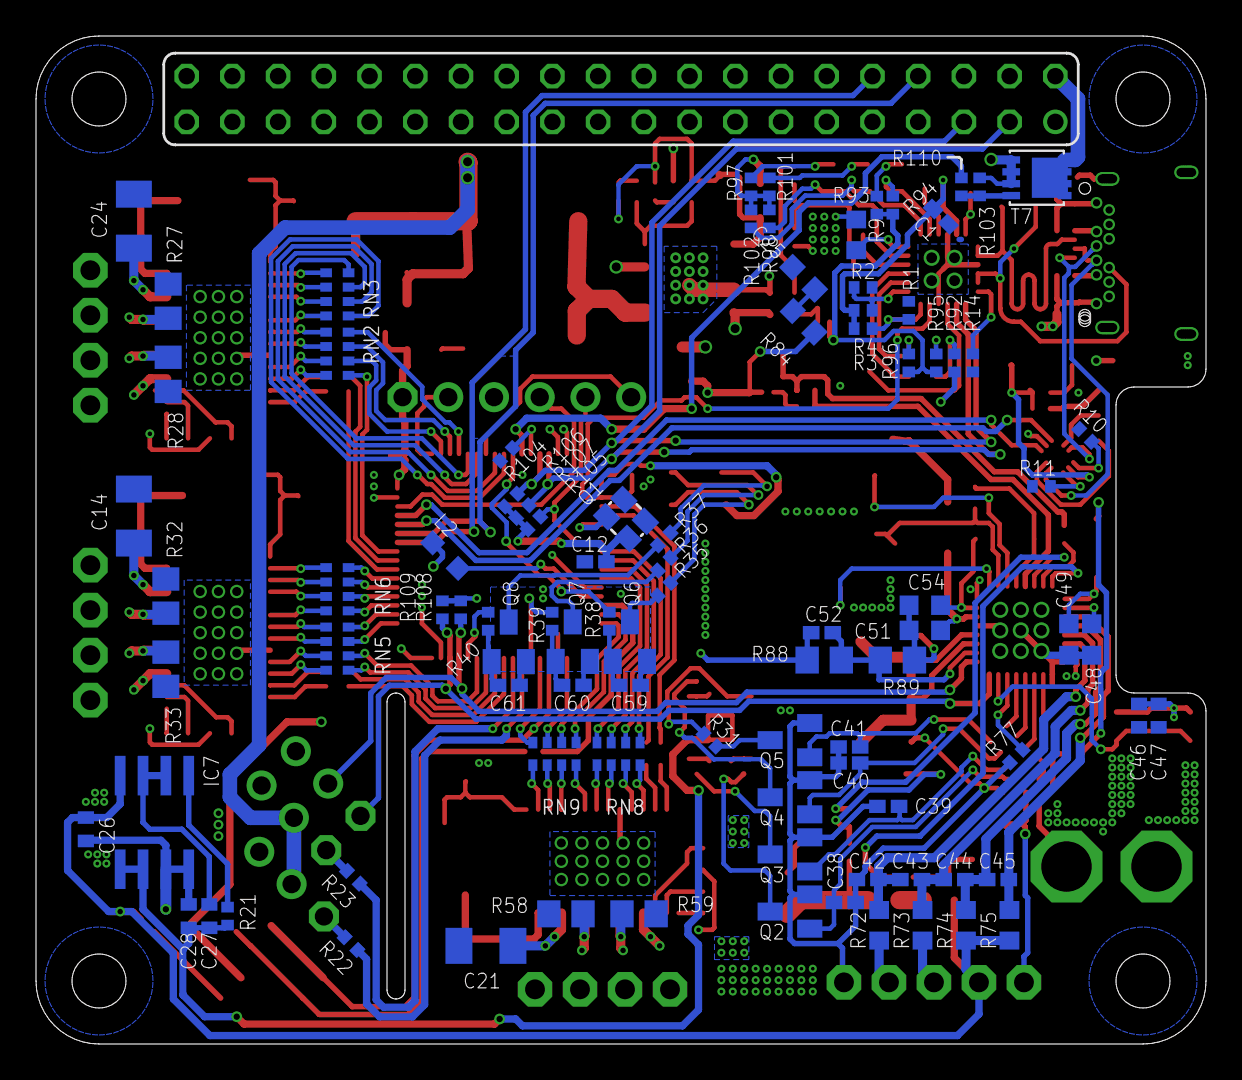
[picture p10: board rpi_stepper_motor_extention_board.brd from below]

Board: 4 copper layers, 65.0 x 56.0 mm, 217 parts (94 on the bottom side), 226 nets.

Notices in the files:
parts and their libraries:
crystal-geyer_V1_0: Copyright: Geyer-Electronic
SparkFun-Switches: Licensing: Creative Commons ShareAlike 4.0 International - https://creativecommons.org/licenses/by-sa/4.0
